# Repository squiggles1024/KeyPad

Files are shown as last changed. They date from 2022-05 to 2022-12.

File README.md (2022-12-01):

# Custom Gaming KeyPad

My second 'finished' prototype of an embedded systems project. This is largely inspired by professional gaming 'keypads' developed by Logitech and Razer. They are essentially a small formfactor keyboard with a button layout that is (supposedly) more ergonomic for gaming. It was programmed on an STM32F4 "Black Pill Board".

This keypad was designed for use with "MMO" style games that require large numbers of easily accessible keys that will map to your character's attacks, abilities, and interface windows (such as the 'pause' menu). In particular, this was designed with World of Warcraft in mind. It features 64 buttons, an LCD capactive touch screen with 12 'touch buttons', and an analog joystick which currently funtions as a mousewheel. The purpose of this project was largely to see how many keybinds I could comfortably fit in the footprint of a typical 'gaming keypad'.
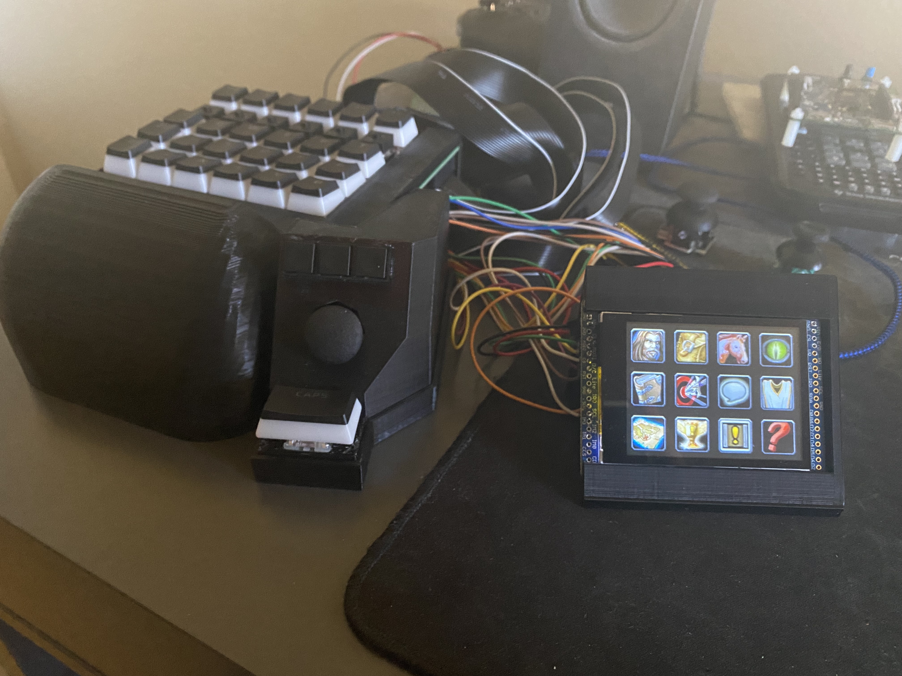
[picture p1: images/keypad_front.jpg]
Final Prototype


The original design was to use 6 "Mouse Wheels" that could be tilted left, tilted right, pushed in, scrolled up, and scrolled down, which would allow 5 functions in a single hardware device. Ultimately this was scrapped because the 3D Print for the wheels and mechanical parts to make the tilting work were too fragile.
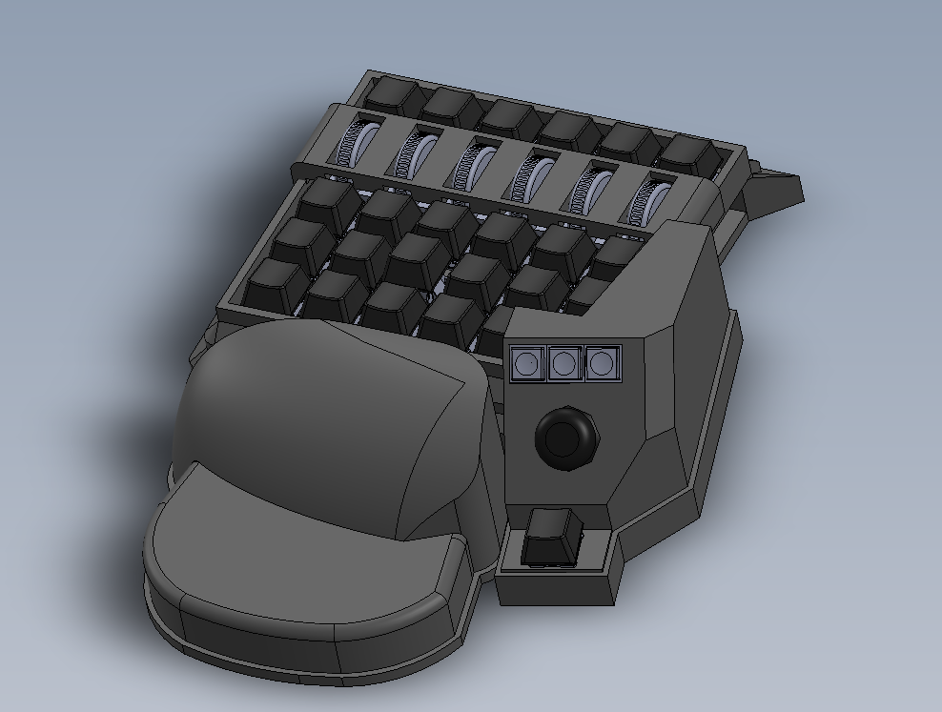
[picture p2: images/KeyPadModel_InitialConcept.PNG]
Initial Model


The buttons in the 2nd row from the top are "Navigation switches". These can be tilted in 4 directions and pressed in; thus this single device can function as 5 different buttons. These replaced the mouse wheel idea.
All keys, switches, touch buttons, and joy stick directions (up to 8) can be programmed to function as 1 modifier key (ctrl, shift, alt), a mouse click, mousewheel movement, or a keystroke. As an example, a button can be programmed to be the equivalent of pressing "Mouse Button 3", "Q", "Left Ctrl", and "Mouse Wheel Up" at the same time. It cannot do multiple keystrokes/mouse clicks at one: as in pressing a key cannot be the equivalent of pressing "Q + W", or "Mouse 4 + Mouse 5" simultaneously.
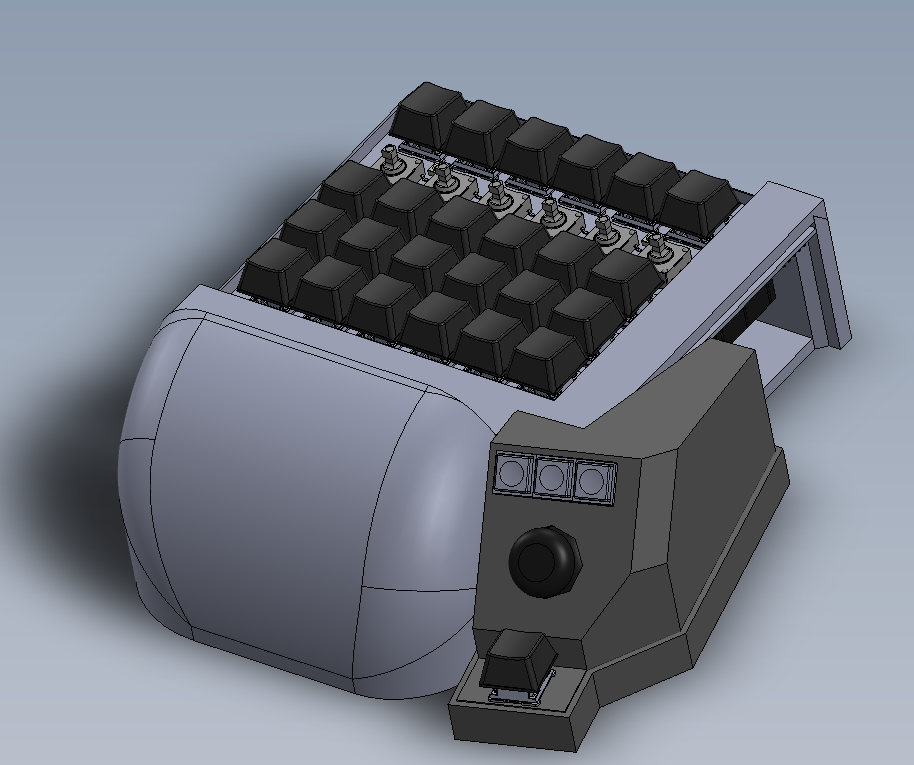
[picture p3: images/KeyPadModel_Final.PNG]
KeyPadModel Final


The touchscreen is intended to be used to access the users 'menu interface windows' such as opening their inventory or friends list (buttons that don't need to be pressed often or need to be easily within reach in a pinch). The icons are stored as uchar arrays in RGB888 format in the mcu's flash which is programmed into the lcd screen at startup.
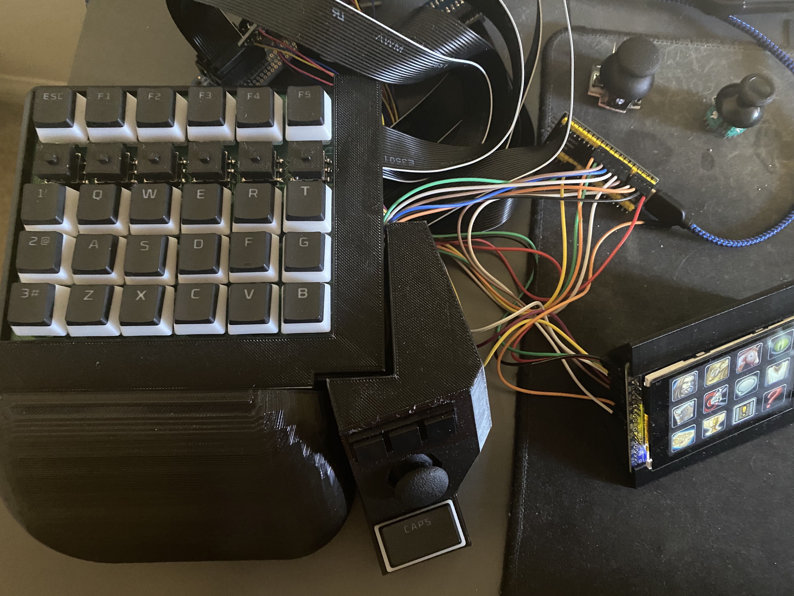
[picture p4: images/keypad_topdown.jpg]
TopDownView


The Black pill board does not have enough GPIO pins to serve all 64 buttons, and the SPI bus for the touch screen, so GPIO expander bonnets were used instead (thank you Adafruit). There are 4 expanders in total, and these are polled using DMA in a round-robin fashion. The touch screen was also a COTS part from Adafruit.
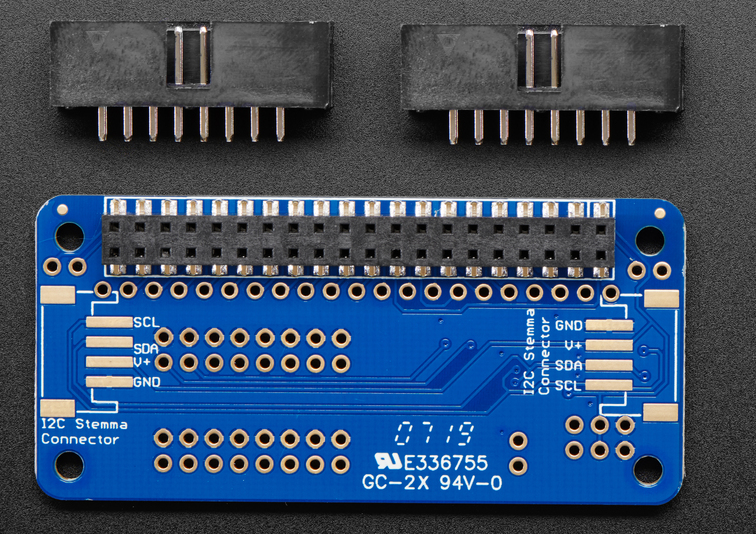
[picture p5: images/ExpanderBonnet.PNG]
Bonnet


The board design is electrically simple, but mechanically complex. It is effectively a motherboard that interfaces the LCD screen, expander bonnets, and joystick with the microcontroller, the the buttons with the expander bonnets. On the bottom of the board are 4 addressable LEDs (sometimes referred to as "neo pixels).
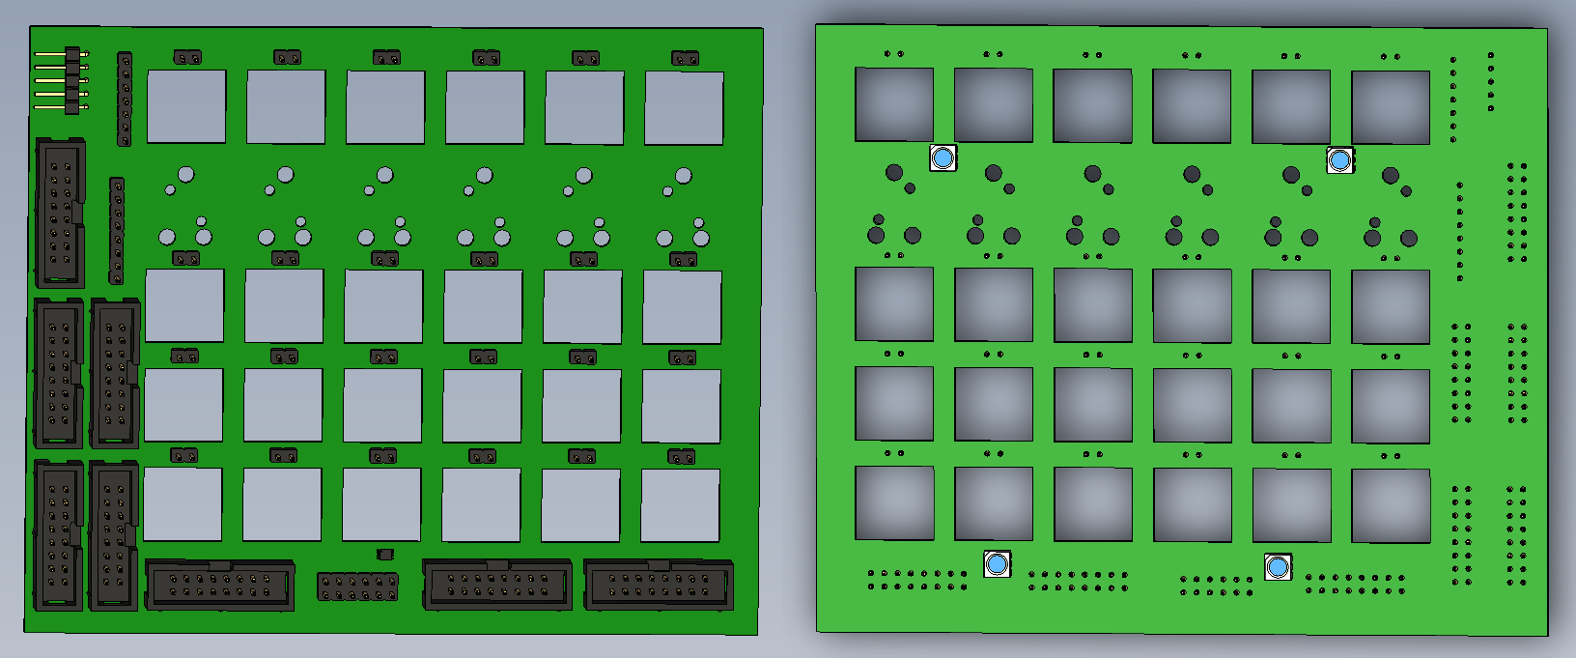
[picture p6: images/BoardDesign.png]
Board Design


Known Issue: The LEDs currently do not work. I'm confident that the firmware to make them work in theory is correct, but upon hooking up the PWM signal to a scope, the rise and fall time appear to be too long (The PWM signal looks sinusoidal). Best guess is the wires are too long and there's too much stray capacitance on the PCBA. Also, the cabling ended up taking way more space than anticipated, thus I need to find something to do about the cables because it's currently a mess.

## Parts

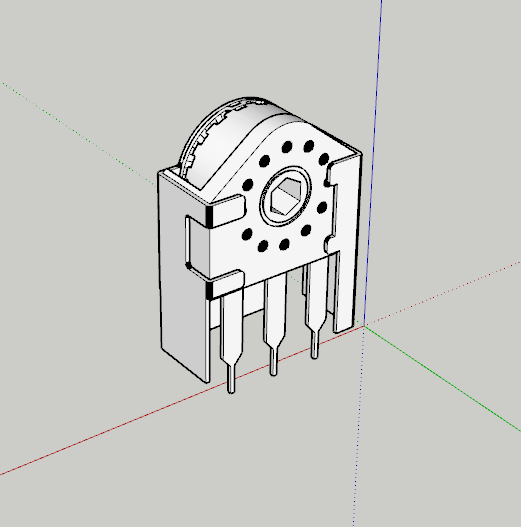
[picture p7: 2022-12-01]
KeyPad_Project/CAD Parts/rotary-encoder-mouse-1.snapshot.1/Rotary encoder mouse/Capturar 1.PNG

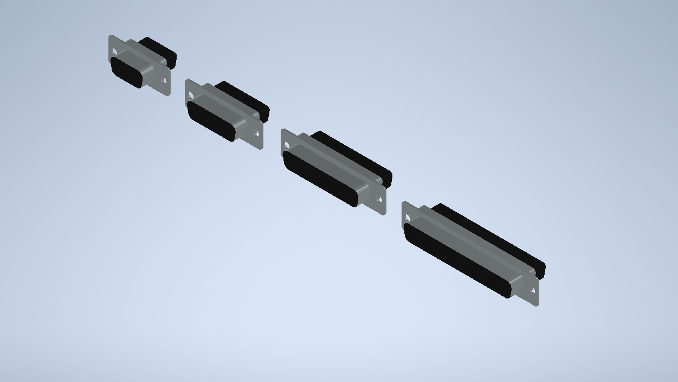
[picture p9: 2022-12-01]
KeyPad_Project/CAD Parts/d-sub-connector-femaile-1.snapshot.1/femaile/db.PNG

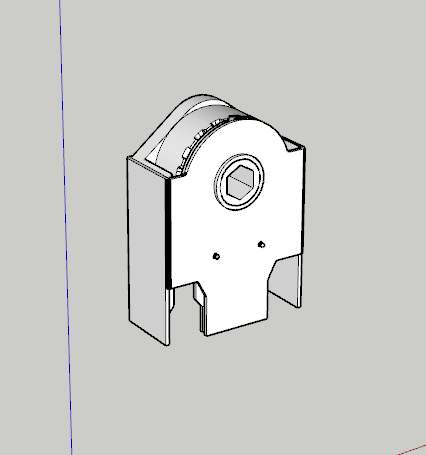
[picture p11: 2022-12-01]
KeyPad_Project/CAD Parts/rotary-encoder-mouse-1.snapshot.1/Rotary encoder mouse/Capturar 2.PNG

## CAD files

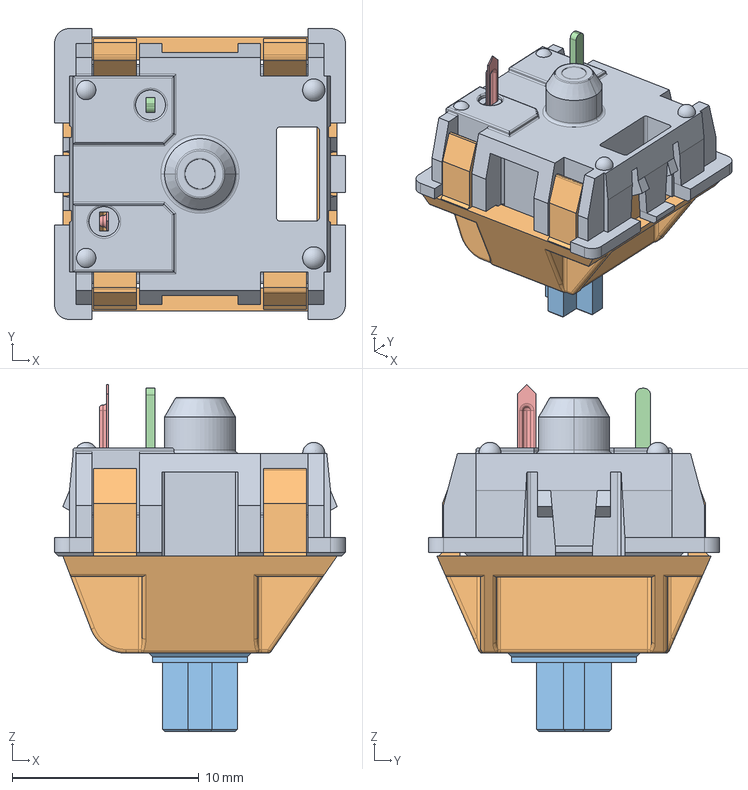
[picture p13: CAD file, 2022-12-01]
KeyPad_Project/CAD Parts/cherry-mx-1.snapshot.3/asm_mx_asm_PLATE.stp
15.6 x 15.6 x 18.6 mm
MX_DOWN
MX_UP
UP_MX
MX_PIN
MX_SPRING
MX_CLICK

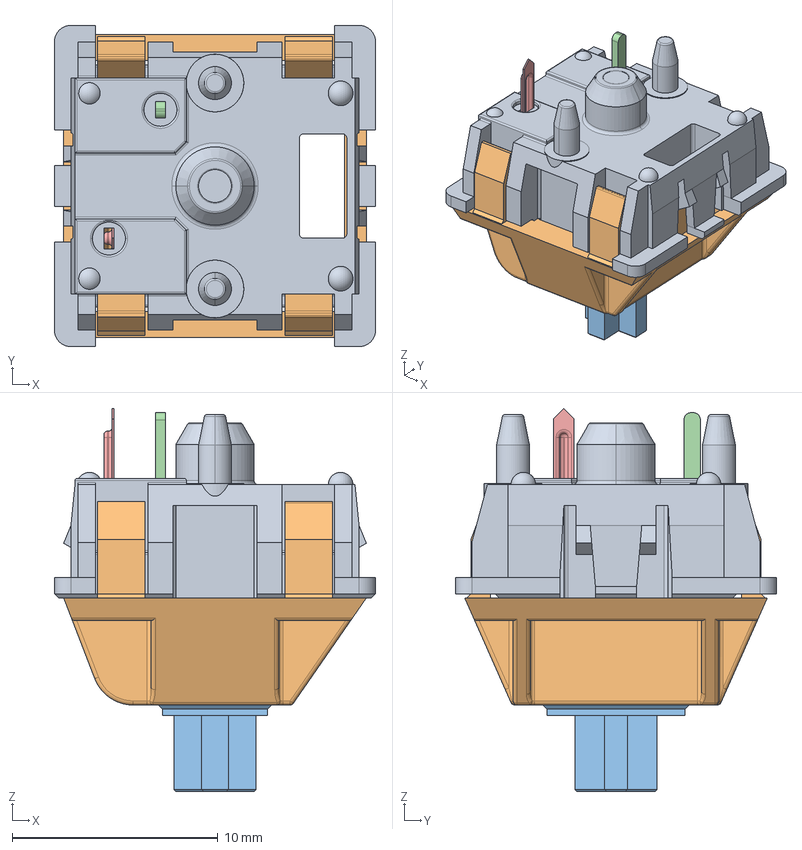
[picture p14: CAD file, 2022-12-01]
KeyPad_Project/CAD Parts/cherry-mx-1.snapshot.3/asm_mx_asm_PCB.stp
15.6 x 15.6 x 18.6 mm
MX_DOWN
MX_UP
UP_MX
MX_PIN
MX_SPRING
MX_CLICK

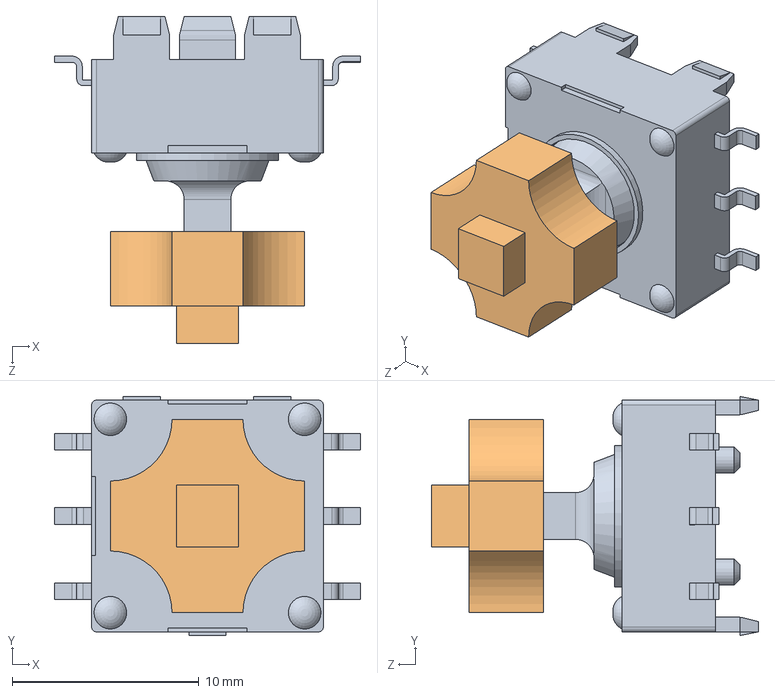
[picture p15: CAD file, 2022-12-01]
KeyPad_Project/CAD Parts/KeyCapAssembly.SLDASM
16.4 x 12.8 x 17.5 mm
JS5208.step
KeyCap

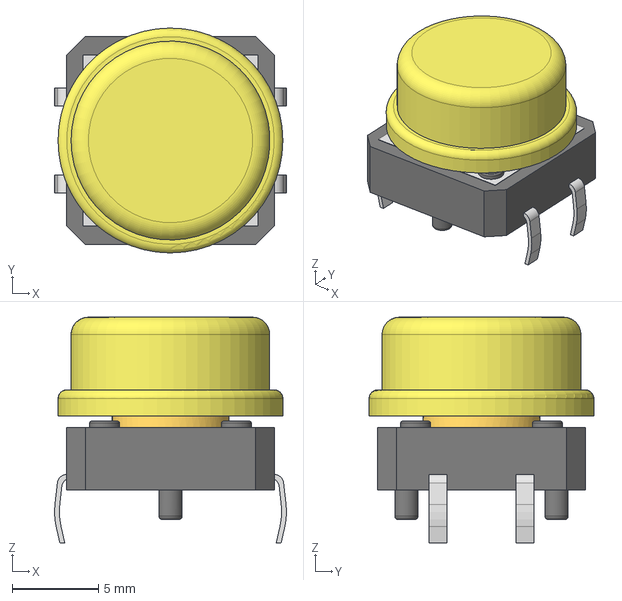
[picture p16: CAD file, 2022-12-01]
KeyPad_Project/CAD Parts/12mm-button-without-cap-with-round-square-cap-1.snapshot.3/12mmx12mm With Yellow cap round.stp
13.4 x 13.0 x 13.0 mm

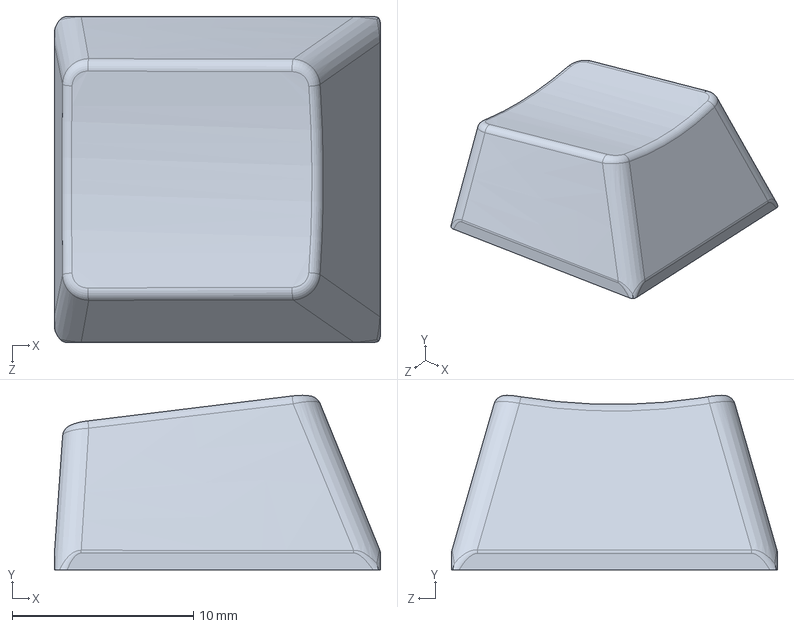
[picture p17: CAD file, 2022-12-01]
KeyPad_Project/CAD Parts/cherry-mx-keycap-1.snapshot.3/Cherry MX Keycap.SLDPRT
18.0 x 9.64 x 18.0 mm

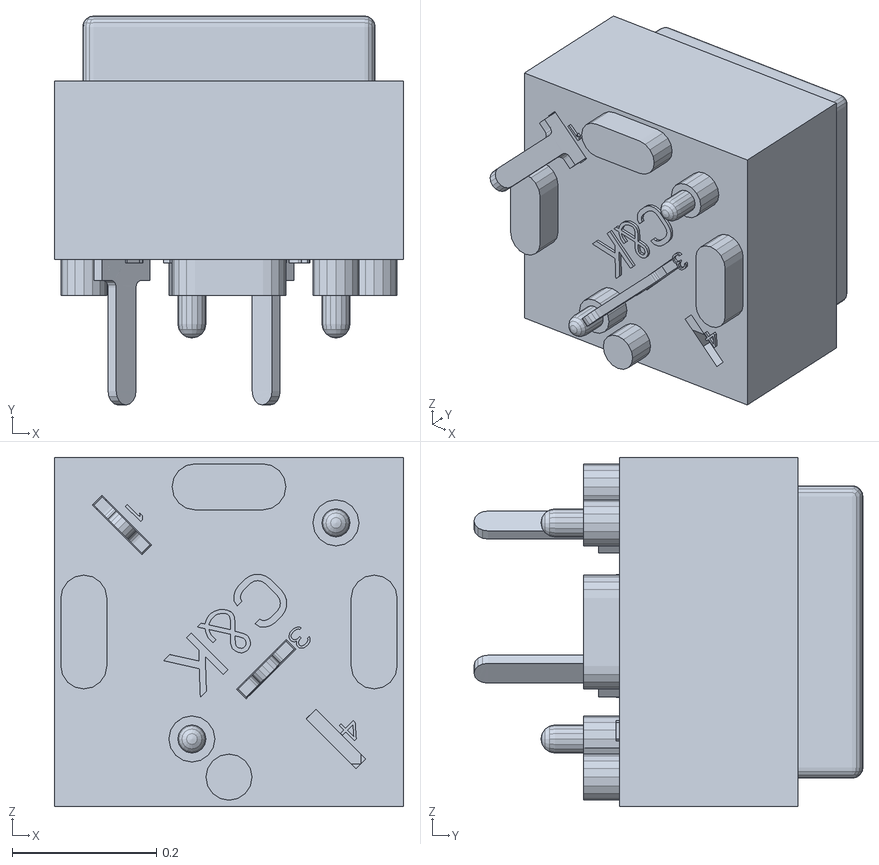
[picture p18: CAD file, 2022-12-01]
KeyPad_Project/CAD Parts/CKCOMPONENTS_KS11R22CBD/KS11R22CBD.stl
0.485 x 0.54 x 0.485

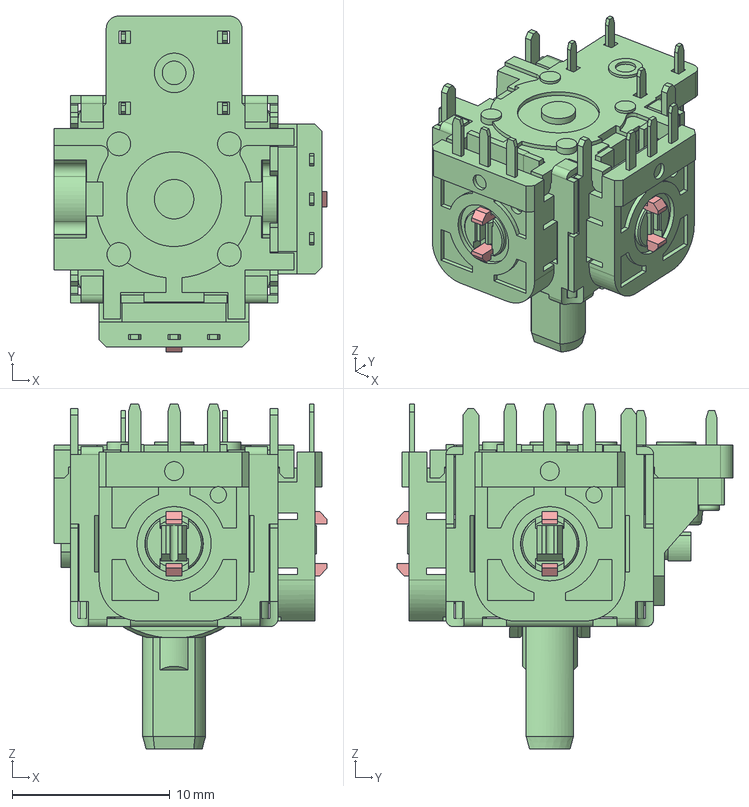
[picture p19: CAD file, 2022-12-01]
KeyPad_Project/CAD Parts/CKCOMPONENTS_THB001P/THB001P.stp
17.3 x 21.3 x 21.9 mm
THB001P_PART8
THB001P_PART7
THB001P_PART6
THB001P_PART5
THB001P_PART4
THB001P_PART3
THB001P_PART2
THB001P_PART1

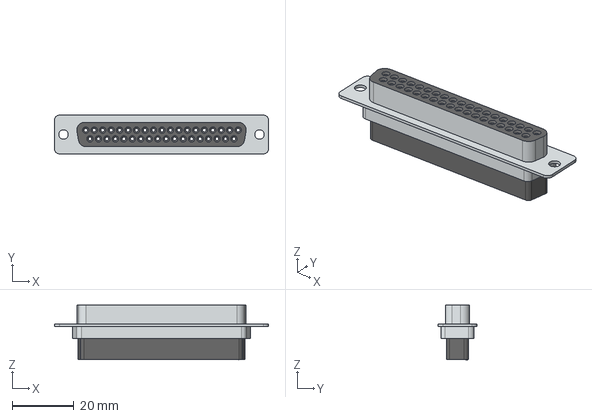
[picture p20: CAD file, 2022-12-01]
KeyPad_Project/CAD Parts/d-sub-connector-femaile-1.snapshot.1/femaile/db37.stp
69.3 x 12.5 x 17.7 mm

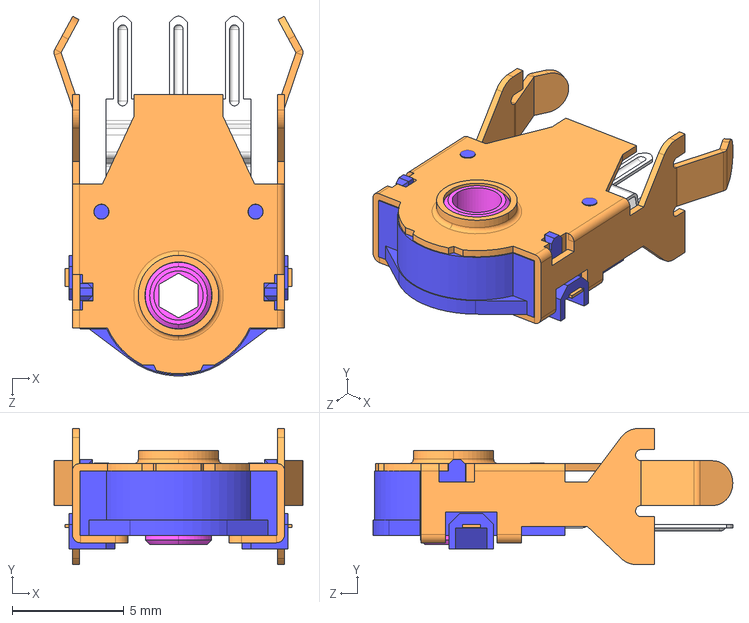
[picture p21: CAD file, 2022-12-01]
KeyPad_Project/CAD Parts/ec10e1220501/EC10E1220501.STEP
11.1 x 6.10 x 16.1 mm

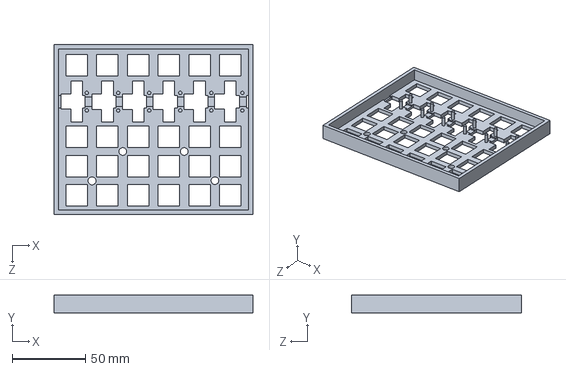
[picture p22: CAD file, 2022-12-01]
KeyPad_Project/CAD Parts/Housing2.SLDPRT
136.0 x 12.0 x 116.0 mm

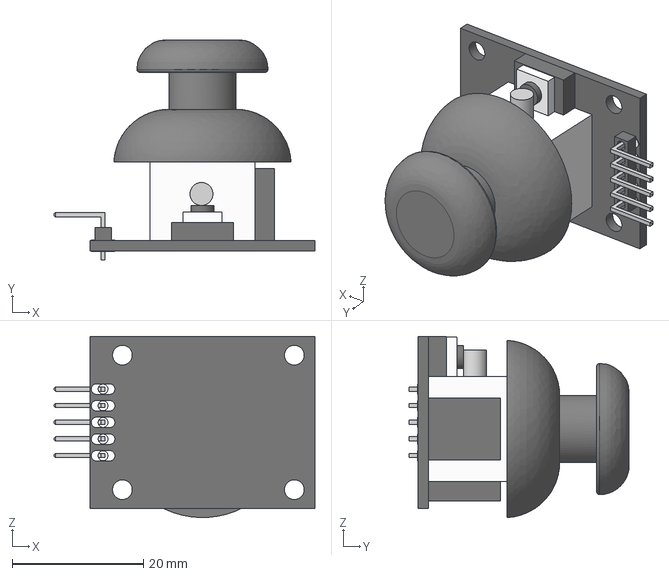
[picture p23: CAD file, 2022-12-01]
KeyPad_Project/CAD Parts/joy-stick-4.snapshot.1 (1)/joy_stick_a2/joy_stick_a2.iges
39.8 x 33.6 x 27.6 mm

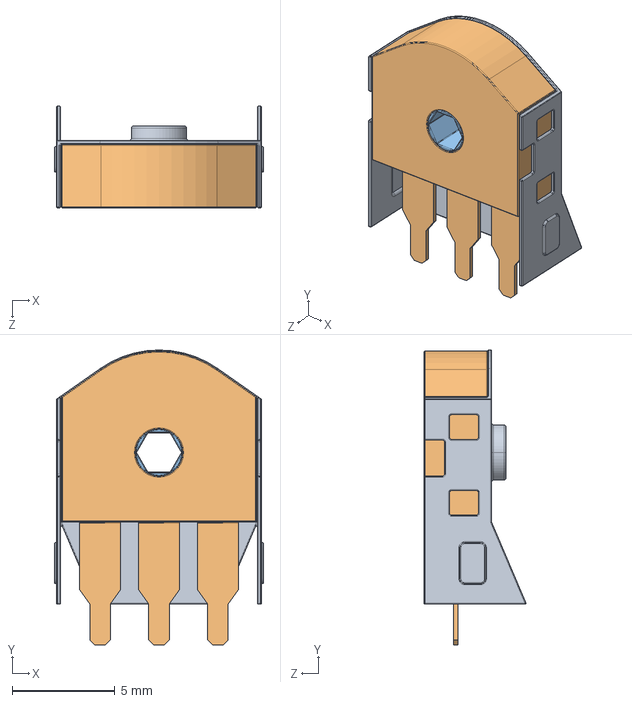
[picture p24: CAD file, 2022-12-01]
KeyPad_Project/CAD Parts/rotary-encoder-for-mouse-1.snapshot.2/Rotary Encoder for Mouse.STEP
10.2 x 14.4 x 4.97 mm

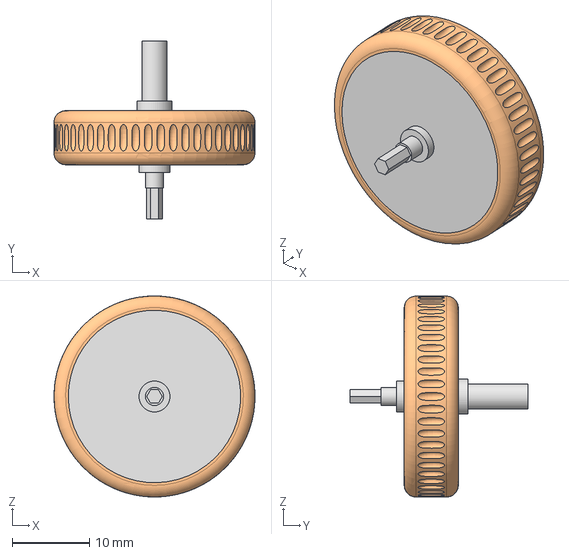
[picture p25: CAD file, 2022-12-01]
KeyPad_Project/CAD Parts/steelseries-sensei-scroll-wheel-1.snapshot.1/Sensei Scroll Wheel.step
26.0 x 23.0 x 26.0 mm

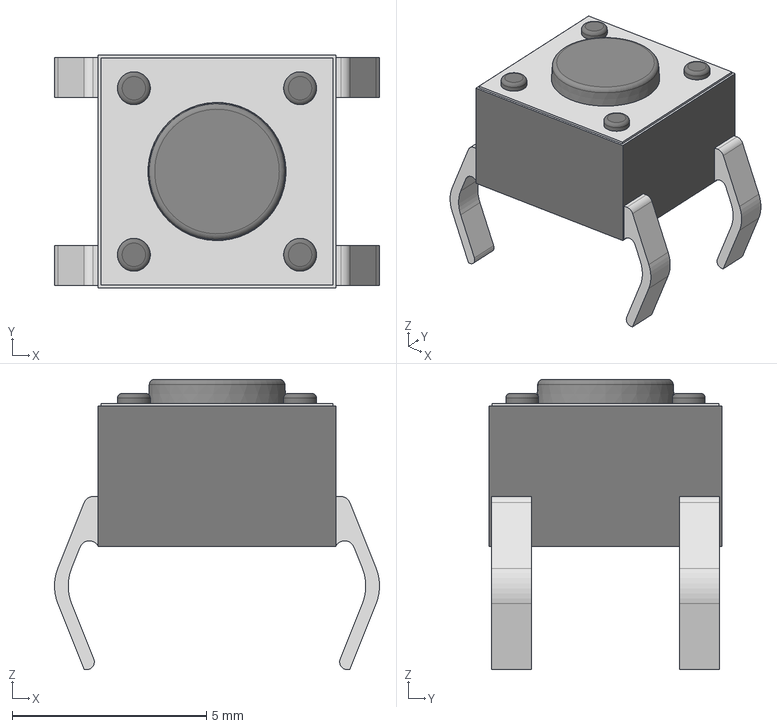
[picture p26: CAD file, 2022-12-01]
KeyPad_Project/CAD Parts/tactile-switch-thru-6mm-series-1.snapshot.25/Tactal Switch -Thru (6mmx 6mmx4.3mm).stp
8.37 x 5.99 x 7.48 mm

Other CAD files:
KeyPad_Project/ECAD/B4B-PH-SM4-TB/B4B-PH-SM4-TB.step
KeyPad_Project/ECAD/JS5208/JS5208.step
KeyPad_Project/CAD Parts/12mm-button-without-cap-with-round-square-cap-1.snapshot.3/12mmx12mm With White cap square.stp
KeyPad_Project/CAD Parts/d-sub-connector-femaile-1.snapshot.1/femaile/db9.stp
KeyPad_Project/CAD Parts/12mm-button-without-cap-with-round-square-cap-1.snapshot.3/12mmx12mm With Black cap round.stp
KeyPad_Project/CAD Parts/12mm-button-without-cap-with-round-square-cap-1.snapshot.3/12mmx12mm With Black cap square.stp
KeyPad_Project/CAD Parts/12mm-button-without-cap-with-round-square-cap-1.snapshot.3/12mmx12mm With Blue cap round.stp
KeyPad_Project/CAD Parts/12mm-button-without-cap-with-round-square-cap-1.snapshot.3/12mmx12mm With Blue cap square.stp
KeyPad_Project/CAD Parts/12mm-button-without-cap-with-round-square-cap-1.snapshot.3/12mmx12mm With Green cap round.stp
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

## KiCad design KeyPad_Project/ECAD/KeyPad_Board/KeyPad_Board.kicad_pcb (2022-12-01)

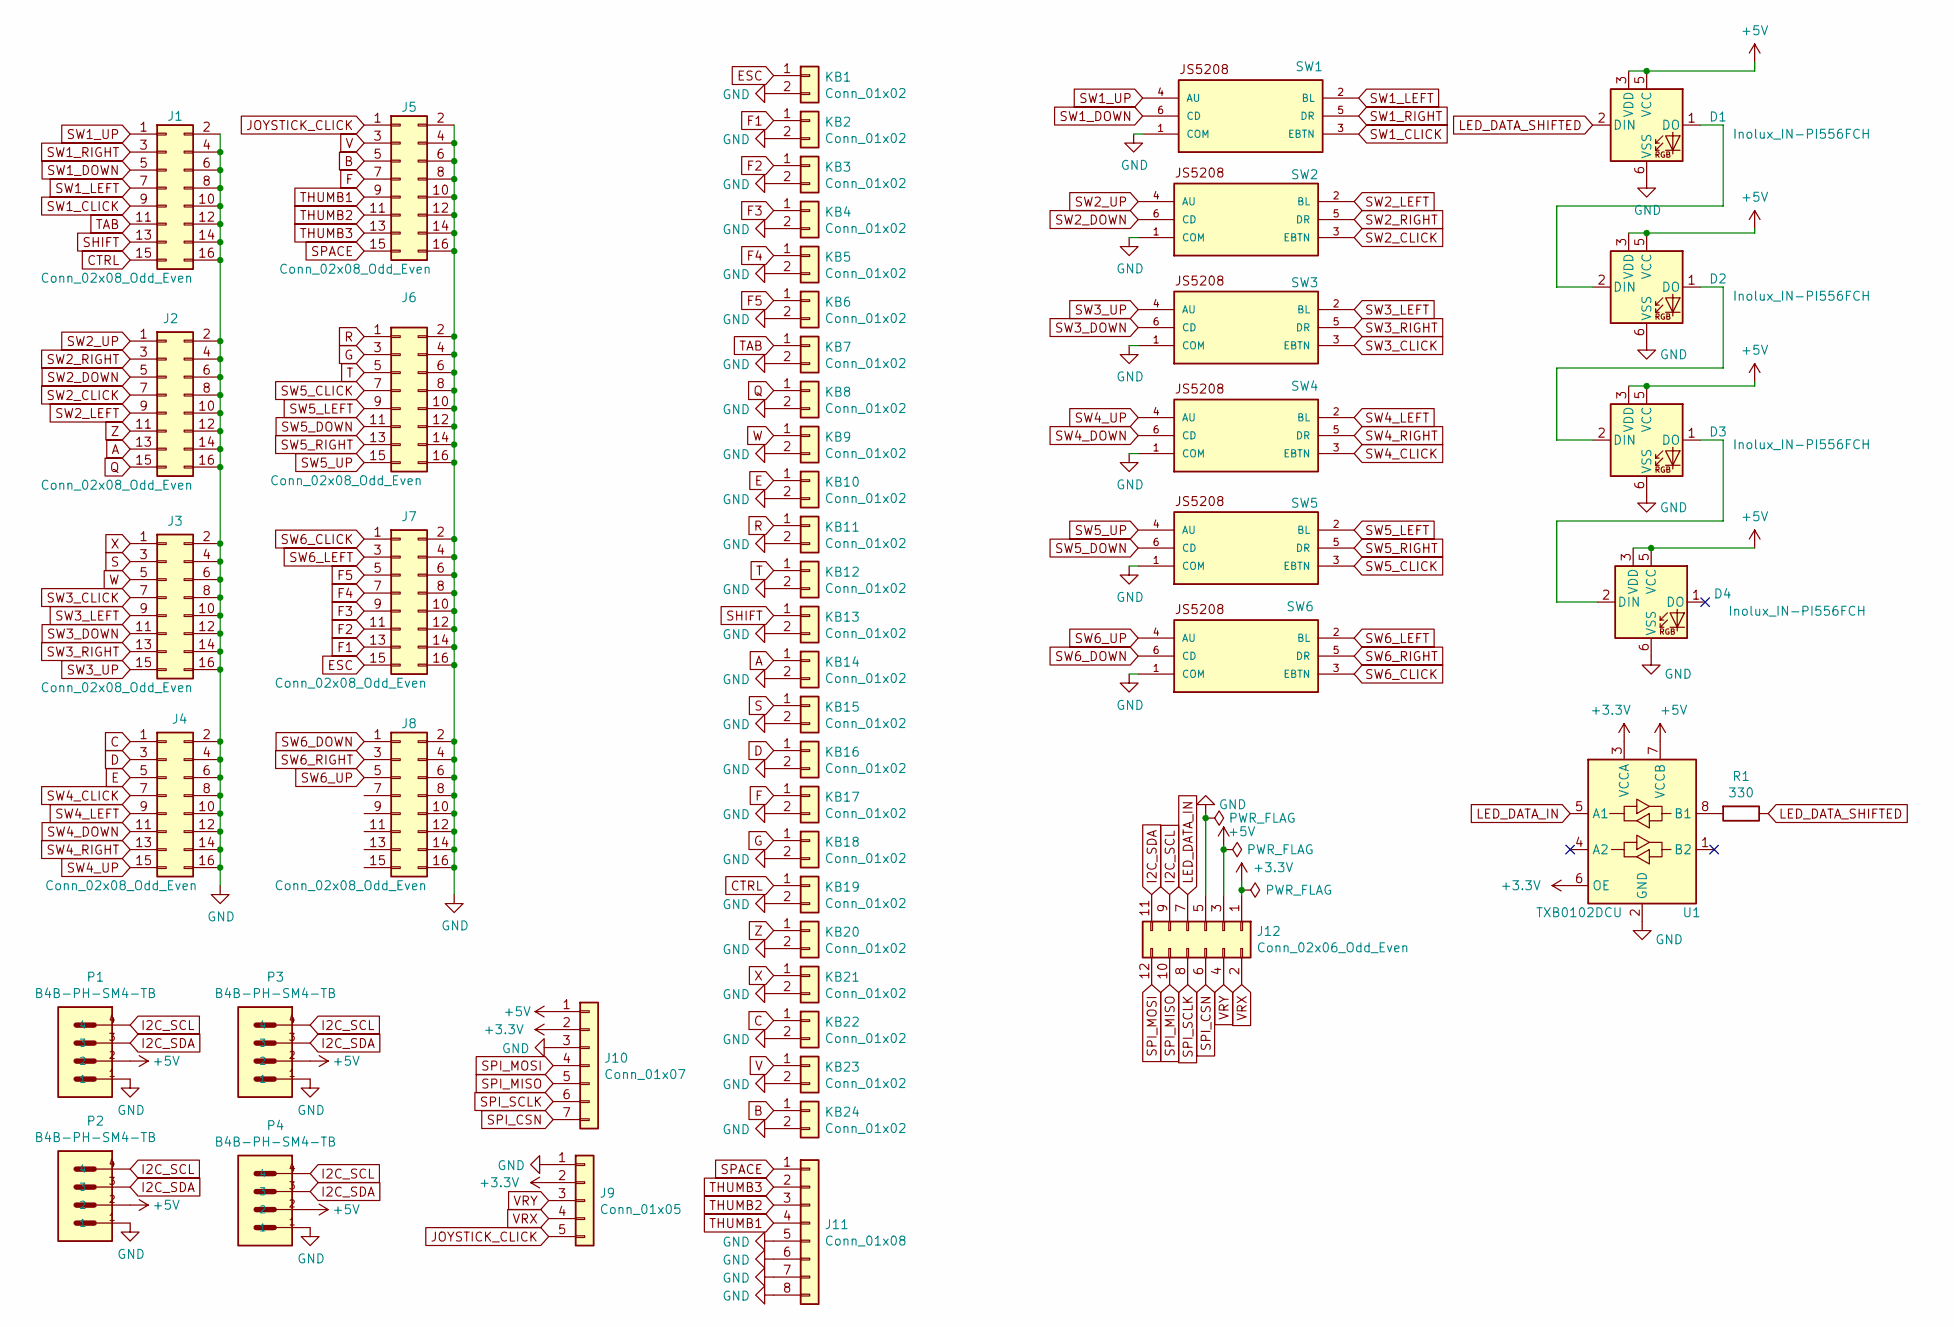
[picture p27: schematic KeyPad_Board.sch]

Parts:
D1, D2, D3, D4: Inolux_IN-PI556FCH; LED_WS2812_PLCC6_5.0x5.0mm_P1.6mm
J1, J2, J3, J4, J5, J6, J7, J8: Conn_02x08_Odd_Even; IDC-Header_2x08_P2.54mm_Vertical
J9: Conn_01x05; PinHeader_1x05_P2.54mm_Horizontal
J10: Conn_01x07; PinHeader_1x07_P2.54mm_Vertical
J11: Conn_01x08; PinHeader_1x08_P2.54mm_Vertical
J12: Conn_02x06_Odd_Even; PinHeader_2x06_P2.54mm_Vertical
KB1, KB2, KB3, KB4, KB5, KB6, KB7, KB8, KB9, KB10, KB11, KB12, KB13, KB14, KB15, KB16, KB17, KB18, KB19, KB20, KB21, KB22, KB23, KB24: Conn_01x02; PinHeader_1x02_P2.54mm_Vertical
P1, P2, P3, P4: B4B-PH-SM4-TB; JST_B4B-PH-SM4-TB
R1: 330; R_0603_1608Metric_Pad0.98x0.95mm_HandSolder
SW1, SW2, SW3, SW4, SW5, SW6: JS5208; JS5208_PKG
U1: TXB0102DCU; VSSOP-8_2.4x2.1mm_P0.5mm

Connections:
+3V3: J9.2, J10.2, J12.1, U1.3 (VCCA), U1.6 (OE)
+5V: D1.3 (VDD), D1.5 (VCC), D2.3 (VDD), D2.5 (VCC), D3.3 (VDD), D3.5 (VCC), D4.3 (VDD), D4.5 (VCC), J10.1, J12.3, P1.2, P2.2, P3.2, P4.2, U1.7 (VCCB)
A: J2.13, KB14.1
B: J5.5, KB24.1
C: J4.1, KB22.1
CTRL: J1.15, KB19.1
D: J4.3, KB16.1
E: J4.5, KB10.1
ESC: J7.15, KB1.1
F: J5.7, KB17.1
F1: J7.13, KB2.1
F2: J7.11, KB3.1
F3: J7.9, KB4.1
F4: J7.7, KB5.1
F5: J7.5, KB6.1
G: J6.3, KB18.1
GND: D1.6 (VSS), D2.6 (VSS), D3.6 (VSS), D4.6 (VSS), J1.2, J1.4, J1.6, J1.8, J1.10, J1.12, J1.14, J1.16, J2.2, J2.4, J2.6, J2.8, J2.10, J2.12, J2.14, J2.16, J3.2, J3.4, J3.6, J3.8, J3.10, J3.12, J3.14, J3.16, J4.2, J4.4, J4.6, J4.8, J4.10, J4.12, J4.14, J4.16, J5.2, J5.4, J5.6, J5.8, J5.10, J5.12, J5.14, J5.16, J6.2, J6.4, J6.6, J6.8, J6.10, J6.12, J6.14, J6.16, J7.2, J7.4, J7.6, J7.8, J7.10, J7.12, J7.14, J7.16, J8.2, J8.4, J8.6, J8.8, J8.10, J8.12, J8.14, J8.16, J9.1, J10.3, J11.5, J11.6, J11.7, J11.8, J12.5, KB1.2, KB2.2, KB3.2, KB4.2, KB5.2, KB6.2, KB7.2, KB8.2, KB9.2, KB10.2, KB11.2, KB12.2, KB13.2, KB14.2, KB15.2, KB16.2, KB17.2, KB18.2, KB19.2, KB20.2, KB21.2, KB22.2, KB23.2, KB24.2, P1.1, P2.1, P3.1, P4.1, SW1.1 (COM), SW2.1 (COM), SW3.1 (COM), SW4.1 (COM), SW5.1 (COM), SW6.1 (COM), U1.2 (GND)
I2C_SCL: J12.9, P1.4, P2.4, P3.4, P4.4
I2C_SDA: J12.11, P1.3, P2.3, P3.3, P4.3
JOYSTICK_CLICK: J5.1, J9.5
LED_DATA_IN: J12.7, U1.5 (A1)
LED_DATA_SHIFTED: D1.2 (DIN), R1.1
unnamed: D1.1 (DO), D2.2 (DIN)
unnamed: D2.1 (DO), D3.2 (DIN)
unnamed: D3.1 (DO), D4.2 (DIN)
unnamed: R1.2, U1.8 (B1)
Q: J2.15, KB8.1
R: J6.1, KB11.1
S: J3.3, KB15.1
SHIFT: J1.13, KB13.1
SPACE: J5.15, J11.1
SPI_CSN: J10.7, J12.6
SPI_MISO: J10.5, J12.10
SPI_MOSI: J10.4, J12.12
SPI_SCLK: J10.6, J12.8
SW1_CLICK: J1.9, SW1.3 (EBTN)
SW1_DOWN: J1.5, SW1.6 (CD)
SW1_LEFT: J1.7, SW1.2 (BL)
SW1_RIGHT: J1.3, SW1.5 (DR)
SW1_UP: J1.1, SW1.4 (AU)
SW2_CLICK: J2.7, SW2.3 (EBTN)
SW2_DOWN: J2.5, SW2.6 (CD)
SW2_LEFT: J2.9, SW2.2 (BL)
SW2_RIGHT: J2.3, SW2.5 (DR)
SW2_UP: J2.1, SW2.4 (AU)
SW3_CLICK: J3.7, SW3.3 (EBTN)
SW3_DOWN: J3.11, SW3.6 (CD)
SW3_LEFT: J3.9, SW3.2 (BL)
SW3_RIGHT: J3.13, SW3.5 (DR)
SW3_UP: J3.15, SW3.4 (AU)
SW4_CLICK: J4.7, SW4.3 (EBTN)
SW4_DOWN: J4.11, SW4.6 (CD)
SW4_LEFT: J4.9, SW4.2 (BL)
SW4_RIGHT: J4.13, SW4.5 (DR)
SW4_UP: J4.15, SW4.4 (AU)
SW5_CLICK: J6.7, SW5.3 (EBTN)
SW5_DOWN: J6.11, SW5.6 (CD)
SW5_LEFT: J6.9, SW5.2 (BL)
SW5_RIGHT: J6.13, SW5.5 (DR)
SW5_UP: J6.15, SW5.4 (AU)
SW6_CLICK: J7.1, SW6.3 (EBTN)
SW6_DOWN: J8.1, SW6.6 (CD)
SW6_LEFT: J7.3, SW6.2 (BL)
SW6_RIGHT: J8.3, SW6.5 (DR)
SW6_UP: J8.5, SW6.4 (AU)
T: J6.5, KB12.1
TAB: J1.11, KB7.1
THUMB1: J5.9, J11.4
THUMB2: J5.11, J11.3
THUMB3: J5.13, J11.2
V: J5.3, KB23.1
VRX: J9.4, J12.2
VRY: J9.3, J12.4
W: J3.5, KB9.1
X: J3.1, KB21.1
Z: J2.11, KB20.1

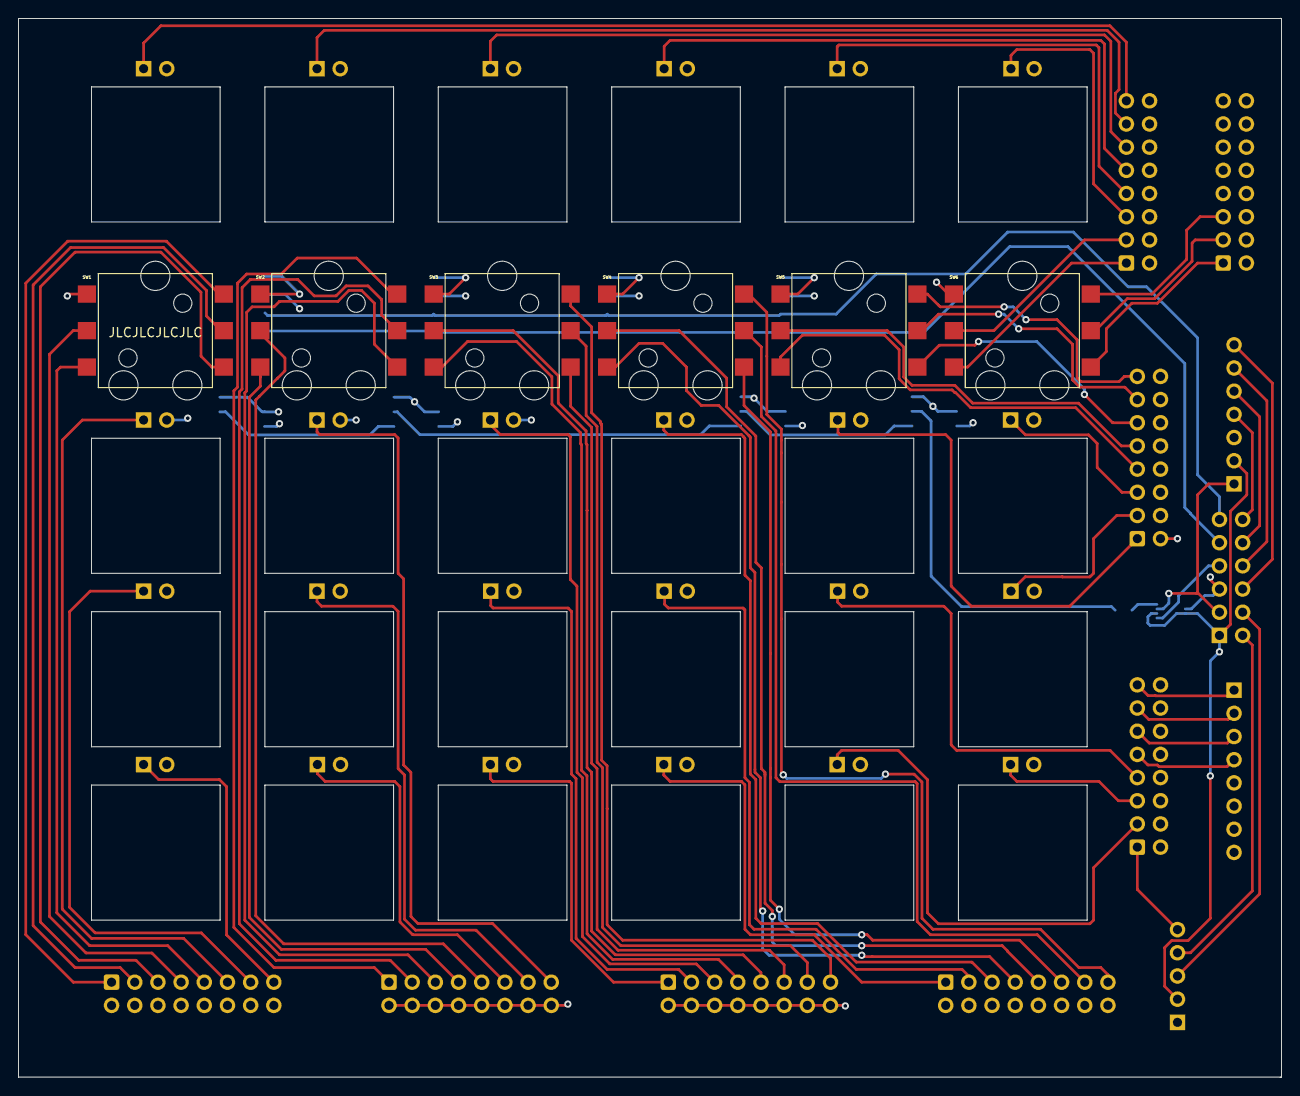
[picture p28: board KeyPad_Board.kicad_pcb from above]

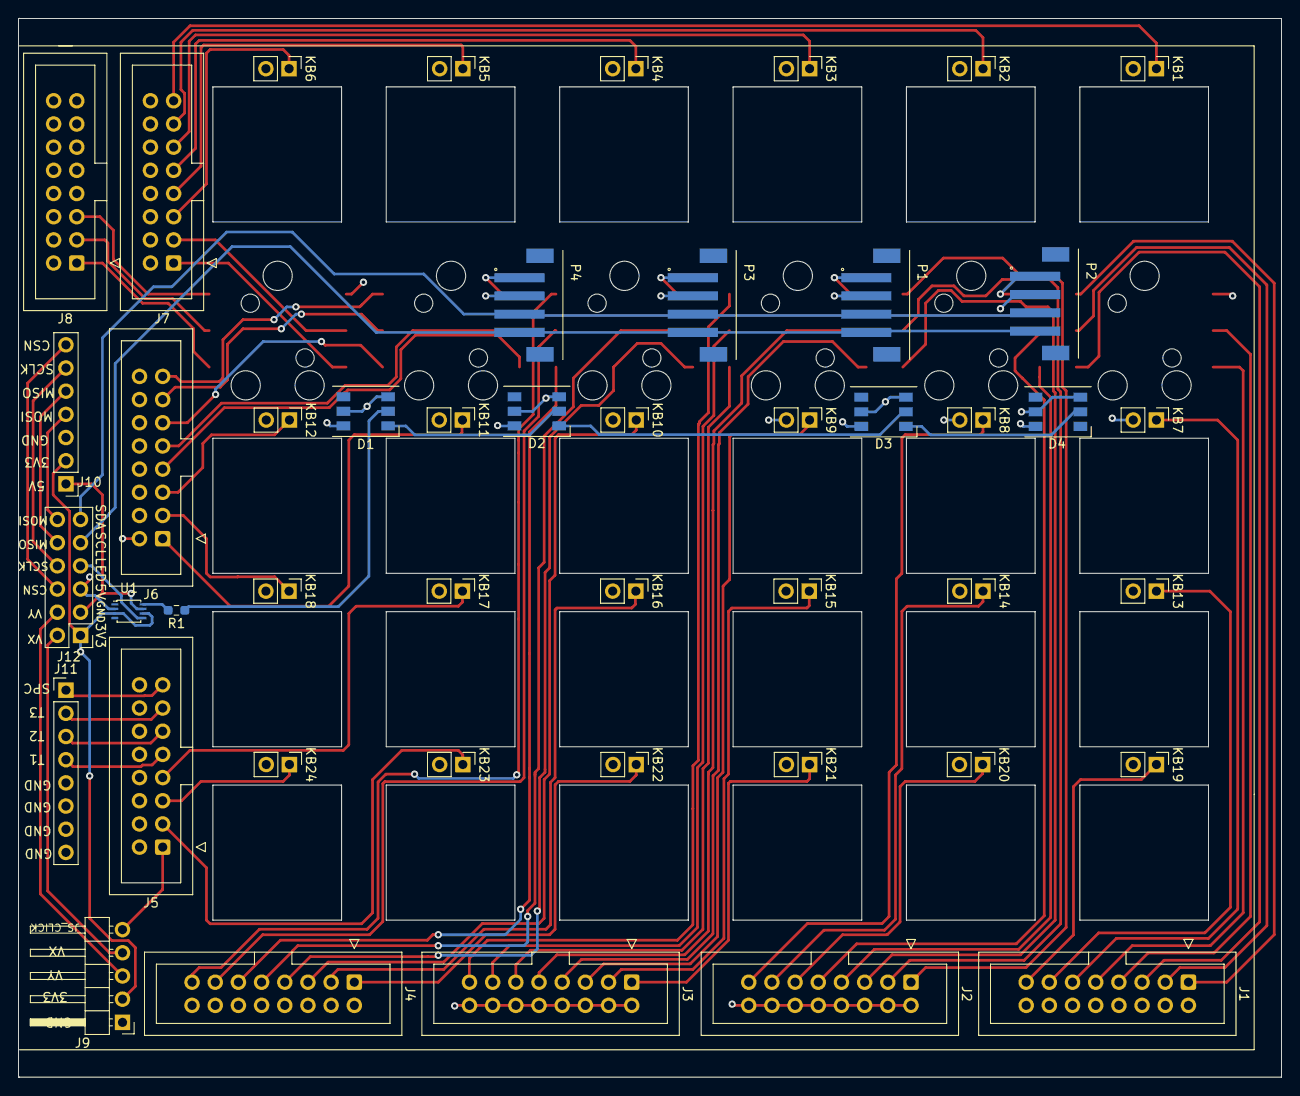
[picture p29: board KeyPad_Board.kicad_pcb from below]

Board: 4 copper layers, 138.4 x 116.0 mm, 52 parts (46 on the bottom side), 76 nets.

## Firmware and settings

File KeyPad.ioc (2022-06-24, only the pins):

Mcu.UserName=STM32F411CEUx
PA10.Signal=USART1_RX
PA11.Signal=USB_OTG_FS_DM
PA12.Signal=USB_OTG_FS_DP
PA3.GPIO_Label=ADC_VX
PA3.Signal=ADCx_IN3
PA4.GPIO_Label=ADC_VY
PA4.Signal=ADCx_IN4
PA5.Signal=SPI1_SCK
PA6.Signal=SPI1_MISO
PA7.Signal=SPI1_MOSI
PA9.Signal=USART1_TX
PB0.GPIO_Label=SPI1_CSN
PB0.Signal=GPIO_Output
PB1.GPIO_Label=DCRS
PB1.Signal=GPIO_Output
PB10.Signal=I2C2_SCL
PB3.Signal=I2C2_SDA
PB4.Signal=S_TIM3_CH1
PB6.Signal=I2C1_SCL
PB7.Signal=I2C1_SDA

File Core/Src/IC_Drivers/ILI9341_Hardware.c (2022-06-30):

/**************************************//**************************************//**************************************
 * Includes
 **************************************//**************************************//**************************************/
#include <ILI9341_Hardware.h>
#include "stm32f4xx_hal.h"
#include "spi.h"
#include "gpio.h"

/**************************************//**************************************//**************************************
 * Private Function Declarations
 **************************************//**************************************//**************************************/
static void ILI9341_CSState(uint8_t state);
static void ILI9341_DCRSState(uint8_t state);

/**************************************//**************************************//**************************************
 * Private Function Definitions
 **************************************//**************************************//**************************************/
/**************************************//**************************************
 *@Brief: Initializes Low level hardware for ILI9431
 *@Params: None
 *@Return: None
 *@Precondition: None
 *@Postcondition: GPIO and SPI Peripherals will be initialized
 **************************************//**************************************/
static void ILI9341_IO_Init(void){
  ILI9341_GPIO_Init();
  ILI9341_SPI_Init();
}

/**************************************//**************************************
 *@Brief: Deinitializes ILI9431 GPIO Pins
 *@Params: None
 *@Return: None
 *@Precondition: ILI9341 hardware should be initialized.
 *@Postcondition: ILI9431 GPIO Pins will be initialized (DCRS, CSN)
 **************************************//**************************************/
static void ILI9341_IO_DeInit(void){
	ILI9341_GPIO_DeInit();
}

/**************************************//**************************************
 *@Brief: Performs "Other" ILI9431 hardware commands
 *@Params: Command to perform
 *@Return: ILI9431 Ok
 *@Precondition: ILI9341 hardware should be initialized.
 *@Postcondition: None
 **************************************//**************************************/
static ILI9341_Status_t ILI9341_IO_ioctl(ILI9341_Cmd_t Command){
    switch(Command){
    case(ILI9341_Delay150):
    		HAL_Delay(150);
            return ILI9341_Ok;
    case(ILI9341_Delay1000):
    		HAL_Delay(1000);
            return ILI9341_Ok;
    default:
    	return ILI9341_Ok;
    }
}

/**************************************//**************************************
 *@Brief: Write to an ILI9431 Register
 *@Params: register to write, data buffer, qty of bytes to write
 *@Return: Err if data is not written, Ok if data is written
 *@Precondition: ILI9341 hardware should be initialized.
 *@Postcondition: ILI9431 register will contain written data
 **************************************//**************************************/
static ILI9341_Status_t ILI9341_IO_WriteReg(uint8_t reg, uint8_t* pdata, uint32_t length){
	ILI9341_CSState(GPIO_PIN_RESET);
	if(reg != 0xFF){
		ILI9341_DCRSState(GPIO_PIN_RESET);
		if(HAL_SPI_Transmit(&hspi1, &reg, 1, 1000) != HAL_OK){
			return ILI9341_Err;
		}
	}

	ILI9341_DCRSState(GPIO_PIN_SET);
	if(length != 0 && reg != 0xFF){
		if(HAL_SPI_Transmit(&hspi1, pdata, length, 1000) != HAL_OK){
			return ILI9341_Err;
		}
	}else if(length != 0 && reg == 0xFF){
        for(uint32_t i = 0; i < length; i = i + 3){
    		if(HAL_SPI_Transmit(&hspi1, pdata, 1, 1000) != HAL_OK){
    			return ILI9341_Err;
    		}

    		if(HAL_SPI_Transmit(&hspi1, pdata + 1, 1, 1000) != HAL_OK){
    			return ILI9341_Err;
    		}

    		if(HAL_SPI_Transmit(&hspi1, pdata + 2, 1, 1000) != HAL_OK){
    			return ILI9341_Err;
    		}
    		if(i == length - 10000){
    			uint8_t j =0;
    			j++;
    		}
        }
	}else {
		ILI9341_CSState(GPIO_PIN_SET);
	}
	return ILI9341_Ok;
}

/**************************************//**************************************
 *@Brief: Reads an ILI9431 Register
 *@Params: register to read, data buffer, bytes to read
 *@Return: Err if data is not read, Ok if data is read
 *@Precondition: ILI9341 hardware should be initialized.
 *@Postcondition: pdata will contain read data
 **************************************//**************************************/
static ILI9341_Status_t ILI9341_IO_ReadReg(uint8_t reg, uint8_t* pdata, uint32_t length){
	ILI9341_CSState(GPIO_PIN_RESET);
	ILI9341_DCRSState(GPIO_PIN_RESET);
	if(HAL_SPI_Transmit(&hspi1, &reg, 1, 1000) != HAL_OK){
        return ILI9341_Err;
	}
	ILI9341_DCRSState(GPIO_PIN_SET);

	if(length != 0){
		if(HAL_SPI_Receive(&hspi1, pdata, length, 1000) != HAL_OK){
			return ILI9341_Err;
		}
	}
	ILI9341_CSState(GPIO_PIN_SET);
	return ILI9341_Ok;
}

/**************************************//**************************************
 *@Brief: Sets/Clears Chip select line of ILI9341
 *@Params: desired state of CSN line
 *@Return: None
 *@Precondition: ILI9341 hardware should be initialized.
 *@Postcondition: CSN line will be set according to state
 **************************************//**************************************/
static void ILI9341_CSState(uint8_t state){
  if(state){
    HAL_GPIO_WritePin(SPI1_CSN_GPIO_Port, SPI1_CSN_Pin, GPIO_PIN_SET);
  } else {
    HAL_GPIO_WritePin(SPI1_CSN_GPIO_Port, SPI1_CSN_Pin, GPIO_PIN_RESET);
  }
}

/**************************************//**************************************
 *@Brief: Sets Data/Command line to high or low
 *@Params: desired state
 *@Return: None
 *@Precondition: ILI9341 hardware should be initialized.
 *@Postcondition:ILI9341 data/command line will be set according to state parameter
 **************************************//**************************************/
static void ILI9341_DCRSState(uint8_t state){
  if(state){
    HAL_GPIO_WritePin(DCRS_GPIO_Port, DCRS_Pin, GPIO_PIN_SET);
  } else {
    HAL_GPIO_WritePin(DCRS_GPIO_Port, DCRS_Pin, GPIO_PIN_RESET);
  }
}

/**************************************//**************************************//**************************************
 * Public Function Definitions
 **************************************//**************************************//**************************************/
ILI9341_IO_Drv_t ILI931_IO = {
		.init = ILI9341_IO_Init,
		.deinit = ILI9341_IO_DeInit,
		.write = ILI9341_IO_WriteReg,
		.read = ILI9341_IO_ReadReg,
		.ioctl = ILI9341_IO_ioctl
};

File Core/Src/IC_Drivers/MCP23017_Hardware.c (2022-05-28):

/*
 * MCP23017_Hardware.c
 *
 *  Created on: May 17, 2022
 *      Author: evanl
 */
/**************************************//**************************************//**************************************
 * Includes
 **************************************//**************************************//**************************************/
#include "MCP23017_Hardware.h"
#include "i2c.h"
#include "gpio.h"
#include "dma.h"
#include "log.h"
/**************************************//**************************************//**************************************
 * Defines / Constants
 **************************************//**************************************//**************************************/
static const uint8_t MCP23017_Address1 = 0x40;
static const uint8_t MCP23017_Address2 = 0x42;
static const uint8_t MCP23017_Address3 = 0x44;
static const uint8_t MCP23017_Address4 = 0x46;
/**************************************//**************************************//**************************************
 * Private Function Definitions
 **************************************//**************************************//**************************************/

/**************************************//**************************************
 *@Brief: Initializes GPIO Clk and I2C Peripheral
 *@Params: None
 *@Return: None
 *@Precondition: None
 *@Postcondition: GPIO B Clk will be enabled and I2C1 Peripheral will be initialized
 **************************************//**************************************/
static void MCP23017_IO_Init(){
	I2C1_DMA_Init();
	I2C_GPIO_Init();
	I2C1_Init();
}

/**************************************//**************************************
 *@Brief: Not yet implemented. Do not de-initialize I2C Peripheral in the event that other devices share the same bus.
 *@Params: None
 *@Return: None
 *@Precondition: None
 *@Postcondition: None
 **************************************//**************************************/
static void MCP23017_IO_DeInit(){
	HAL_NVIC_DisableIRQ(DMA1_Stream0_IRQn);
	HAL_NVIC_ClearPendingIRQ(DMA1_Stream0_IRQn);
}

/**************************************//**************************************
 *@Brief: Writes to a MCP23017 Device Register
 *@Params: MCP23017 Device Address, Register to write to, data to write, data length in bytes
 *@Return: Error if the write fails, otherwise Ok
 *@Precondition: I2C Bus should be initialized
 *@Postcondition: Device register will be written to
 **************************************//**************************************/
static MCP23017_Status_t MCP23017_IO_WriteReg(uint8_t DevAddr, uint8_t RegAddr, uint8_t *Data, uint8_t Length){
	if(HAL_I2C_Mem_Write(&hi2c1, DevAddr, RegAddr, I2C_MEMADD_SIZE_8BIT, Data, Length, 50) != HAL_OK){
		_log(log_i2c,"Write to MCP23017 Reg address %x failed.", RegAddr);
		return MCP23017_Err;
	}
	return MCP23017_Ok;
}

/**************************************//**************************************
 *@Brief: Reads a MCP23017 Device Register
 *@Params: MCP23017 Device Address, Register to read to, data buffer to read into, data length in bytes,
 *@Return: Error if the read fails, otherwise Ok
 *@Precondition: I2C Bus must be initialized
 *@Postcondition: Data buffer will have the read data
 **************************************//**************************************/
static MCP23017_Status_t MCP23017_IO_ReadReg(uint8_t DevAddr, uint8_t RegAddr, uint8_t *Data, uint8_t Length){
	//HAL_I2C_Mem_Read_DMA(hi2c, DevAddress, MemAddress, MemAddSize, pData, Size)
	//if(HAL_I2C_Mem_Read(&hi2c1, DevAddr, RegAddr, I2C_MEMADD_SIZE_8BIT, Data, Length, 50) != HAL_OK){
	if(HAL_I2C_Mem_Read_DMA(&hi2c1, DevAddr, RegAddr, I2C_MEMADD_SIZE_8BIT, Data, Length) != HAL_OK){
		_log(log_i2c,"Read from MCP23017 Reg address %x failed.", RegAddr);
		return MCP23017_Err;
	}
	return MCP23017_Ok;
}

/**************************************//**************************************
 *@Brief: Not Yet Implemented. Function is reserved for other IO control functionality (e.g. IRQ pin reading)
 *@Params: Command
 *@Return: None
 *@Precondition: None
 *@Postcondition: None
 **************************************//**************************************/
static uint8_t MCP23017_IO_ioctl(MCP23017_IO_Cmd_t command){
	return MCP23017_Ok;
}

/**************************************//**************************************
 *@Brief: Writes to MCP23017 Device with Address1
 *@Params: Register to write to, data to write, length of data in bytes
 *@Return: Err if write fails, Ok otherwise
 *@Precondition: I2C Bus must be initialized
 *@Postcondition: Device (w/ Address1) register will be modified
 **************************************//**************************************/
static MCP23017_Status_t MCP23017_IO1_WriteReg(uint8_t RegAddr, uint8_t *Data, uint8_t Length){
	static const uint8_t address = MCP23017_Address1;
    return MCP23017_IO_WriteReg(address, RegAddr, Data, Length);
}
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

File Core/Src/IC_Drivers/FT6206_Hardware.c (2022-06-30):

/*
 * FT6206_Hardware.c
 *
 *  Created on: May 26, 2022
 *      Author: evanl
 */
/**************************************//**************************************//**************************************
 * Includes
 **************************************//**************************************//**************************************/
#include <FT6206_Hardware.h>
#include "i2c.h"
#include "gpio.h"
#include "dma.h"

/**************************************//**************************************//**************************************
 * Private Constants
 **************************************//**************************************//**************************************/
static const uint8_t DevAddr = 0x70;

/**************************************//**************************************//**************************************
 * Private Function Definitions
 **************************************//**************************************//**************************************/
/**************************************//**************************************
 *@Brief: Initializes FT6206 Low Level hardware
 *@Params: None
 *@Return: None
 *@Precondition: None
 *@Postcondition: I2C2, DMA, and GPIO Peripherals will be initialized
 **************************************//**************************************/
static void FT6206_IO_Init(void){
	I2C2_DMA_Init();
	I2C_GPIO_Init();
	I2C2_Init();
}

/**************************************//**************************************
 *@Brief: Disables FT6206 IRQs and clears pending IRQs. Low level IO not deinitialized in case other hardware is using it.
 *@Params: None
 *@Return: None
 *@Precondition: None
 *@Postcondition: DMA1 Stream2 IRQ will be disabled
 **************************************//**************************************/
static void FT6206_IO_DeInit(void){
	HAL_NVIC_DisableIRQ(DMA1_Stream2_IRQn);
	HAL_NVIC_ClearPendingIRQ(DMA1_Stream2_IRQn);
}

/**************************************//**************************************
 *@Brief: Writes to a FT6206 Register
 *@Params: Desired register to write, data to write, quantity of bytes to write
 *@Return: OK on success, Err on failure
 *@Precondition: FT6206 should be initialized
 *@Postcondition: FT6206 device register will be written to.
 **************************************//**************************************/
static FT6206_Status_t FT6206_IO_Write(uint8_t Reg, uint8_t* pdata, uint8_t length){
	if(HAL_I2C_Mem_Write(&hi2c2, DevAddr, Reg, I2C_MEMADD_SIZE_8BIT, pdata, length, 100) != HAL_OK){
		return FT6206_Err;
	}
	return FT6206_Ok;
}

/**************************************//**************************************
 *@Brief: Reads a FT6206 Register
 *@Params: register to read, data buffer, number of bytes to read
 *@Return: OK on success, Err on failure
 *@Precondition: FT6206 should be initialized. pdata must be able to fit length bytes
 *@Postcondition: FT6202 pdata will contain read bytes
 **************************************//**************************************/
static FT6206_Status_t FT6206_IO_Read(uint8_t Reg, uint8_t* pdata, uint8_t length){
	if(HAL_I2C_Mem_Read_DMA(&hi2c2, DevAddr, Reg, I2C_MEMADD_SIZE_8BIT, pdata, length) != HAL_OK){
		return FT6206_Err;
	}
	return FT6206_Ok;
}

/**************************************//**************************************
 *@Brief: Returns FT6206 OK. Modify to add hardware specific functionality
 *@Params: Desired command
 *@Return: FT6206_Ok
 *@Precondition: None (currently)
 *@Postcondition: None (currently)
 **************************************//**************************************/
static uint8_t FT6206_IO_ioctl(FT6206_IO_Cmd_t Command){
	return FT6206_Ok;
}

/**************************************//**************************************//**************************************
 * Public Variable Definitions
 **************************************//**************************************//**************************************/
FT6206_IO_Drv_t FT6202_Drv = {
		.init = FT6206_IO_Init,
		.deinit = FT6206_IO_DeInit,
		.write = FT6206_IO_Write,
		.read = FT6206_IO_Read,
        .ioctl = FT6206_IO_ioctl
};

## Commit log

2022-05-23 Fixed LED timing error
    [SerialLED_Hardware.c]
2022-05-25 Added ILI9431 Driver
2022-05-28 Added I2C2 Support for TouchScreen
2022-05-28 Added I2C2 Support for Touch Screen
2022-05-28 Added Button IRQ Callback
2022-05-28 Modified ISR to support 2 I2C Handles
2022-05-28 Added experimental Timer init function. Unused.
2022-05-28 Initial Commit of TouchScreen driver
2022-05-28 initial commit of touch button driver
2022-05-28 Changed Clock prescalar to fix LCD communication
    [spi.c]
2022-05-28 Changed I2C DMA Init to I2C1 DMA Init
2022-05-28 Added Touch buttons to main
2022-06-24 Adjusted DMA Priorities
2022-06-24 Started Keypad Wrapper/Driver
2022-06-30 Added alpha filter for joystick
2022-12-01 Add CAD Models
    [12mmx12mm With Black cap round.stp, 12mmx12mm With Black cap square.stp, 12mmx12mm With Blue cap round.stp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]

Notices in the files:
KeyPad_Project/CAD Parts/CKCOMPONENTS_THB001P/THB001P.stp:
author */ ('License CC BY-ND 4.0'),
